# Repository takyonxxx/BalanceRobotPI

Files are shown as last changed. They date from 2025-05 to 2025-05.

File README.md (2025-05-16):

# BalanceRobot

A self-balancing robot project powered by Raspberry Pi 5, featuring precise motor control with 2208 brushless gimbal motors, bidirectional ESCs, Bluetooth connectivity, and a mobile app interface.

## 3D Models

You can view and interact with the 3D models directly in GitHub. The 2208 brushless gimbal motors will be placed inside the wheels for a compact, integrated design:

- [View BalanceRobot Frame STL](https://github.com/takyonxxx/BalanceRobotPI/blob/main/stl/F2BNOQ7J839QTHL.stl)
- [View BalanceRobot Wheel STL](https://github.com/takyonxxx/BalanceRobotPI/blob/main/stl/FDFVE76J839QTI2.stl)

## Overview

BalanceRobot is a two-wheeled self-balancing robot that uses PID control algorithms to maintain equilibrium while allowing for remote control via Bluetooth. The project consists of two major components:

1. **Raspberry Pi 5 Control System**: Handles motion sensing, balance control, and motor management
2. **Mobile App Interface**: Provides remote control and parameter adjustment through a user-friendly touch interface

## Features

- **Real-time Balance Control**: Uses MPU6050 IMU for precise angle measurement and PID control
- **High-precision PWM Generation**: Custom high-resolution PWM threads for precise ESC control
- **Powerful Motor System**: 2X 2208 brushless gimbal motors with bidirectional ESCs for responsive movement
- **Bluetooth Low Energy (BLE) Connectivity**: Remote control and telemetry using GATT server
- **Touch-friendly Mobile Interface**: Intuitive control app optimized for touch screens
- **Parameter Tuning**: Adjust PID parameters in real-time for optimal performance
- **Battery Monitoring**: Built-in voltage monitoring with safety cutoff
- **Diagnostic Features**: Performance monitoring and test modes

## Hardware Requirements

- Raspberry Pi 5 (4 or 3 may work with timing adjustments)
- MPU6050 IMU sensor (connected via I2C)
- 2X 2208 brushless gimbal motors
- Bidirectional ESCs (Electronic Speed Controllers)
- Battery (3S LiPo recommended)
- 3D printed chassis with two wheels
- Mobile device with Bluetooth support (for remote control)

## Motor & ESC Setup

The project uses 2208 brushless gimbal motors, which are ideal for self-balancing robots due to their:
- High torque at low RPM
- Precise control
- Compact design
- Low vibration

The bidirectional ESCs provide:
- Forward and reverse control
- Smooth acceleration and deceleration
- Compatible with standard PWM signal from Raspberry Pi
- Quick response time essential for balance corrections

## Connections and Pinouts

### Raspberry Pi 5 GPIO Connections

| Component | Raspberry Pi Pin | Description |
|---|---|---|
| **MPU6050** | | |
| VCC | 3.3V (Pin 1) | Power for MPU6050 |
| GND | GND (Pin 6) | Ground |
| SCL | GPIO 3 (Pin 5) | I2C Clock |
| SDA | GPIO 2 (Pin 3) | I2C Data |
| | | |
| **ESC1 (Right Motor)** | | |
| Signal | GPIO 18 (Pin 12) | PWM Control Signal |
| VCC | External Power Only | Do NOT connect to Raspberry Pi |
| GND | GND (Pin 14) | Common ground |
| | | |
| **ESC2 (Left Motor)** | | |
| Signal | GPIO 19 (Pin 35) | PWM Control Signal |
| VCC | External Power Only | Do NOT connect to Raspberry Pi |
| GND | GND (Pin 39) | Common ground |
| | | |
| **Status LED** | | |
| LED+ | GPIO 22 (Pin 15) | Status indicator |
| LED- | GND (Pin 34) | via appropriate resistor |

### MPU6050 Orientation

For proper balance control, the MPU6050 should be mounted with:
- X-axis aligned parallel to the wheels (pointing forward)
- Y-axis perpendicular to the wheels (pointing to the side)
- Z-axis pointing upward

### Power Distribution

- Power the Raspberry Pi via its USB-C power input
- Power the ESCs and motors with a separate 3S LiPo battery (11.1V) 
- Ensure common ground between Raspberry Pi and ESC power circuits
- Use appropriate voltage regulators/BECs if powering everything from a single battery

### Wiring Diagram

```
                           +---------------+
                           | Raspberry Pi 5|
                           +---------------+
                           | GPIO2  - SDA  |----+
                           | GPIO3  - SCL  |---+|
                           | GPIO18 - ESC1 |--+ ||
                           | GPIO19 - ESC2 |-+ |||
                           | GPIO22 - LED  |+ ||||
                           | GND           |-|-||||
                           | 3.3V          |--|-|||
                           +---------------+  | |||
                                              | |||
+----------+                  +----------+    | |||
| 3S LiPo  |                  | MPU6050  |<---|-||+
| Battery  |                  +----------+    | ||
+----------+                                  | ||
      |                      +------------+   | ||
      +---+           +------| Right ESC  |<--|-|+
          |           |      +------------+   | |
      +---+-----------+--+                    | |
      |      BEC*     |  |   +------------+   | |
      | (if required) |  +---| Left ESC   |<--|-+
      +--------------+      +------------+    |
                                              |
                            +------------+    |
                            | Status LED |<---+
                            +------------+
```
*BEC: Battery Eliminator Circuit (voltage regulator)

## Software Architecture

The project is built using Qt/C++ for the Raspberry Pi control system and features:

### Raspberry Pi Control System

- **RobotControl Class**: Core control system handling balance, motor control, and communication
- **GattServer**: Manages Bluetooth LE communication with the mobile app
- **High-Precision PWM**: Custom thread-based PWM generation for precise ESC control
- **MPU6050 Interface**: I2C communication with the motion sensor
- **PID Controller**: Implements the balance algorithm with adjustable parameters

### Mobile App

- **Touch-Friendly UI**: Optimized for smartphones with intuitive controls
- **Parameter Adjustment**: Real-time PID parameter tuning with intuitive +/- controls
- **Direction Controls**: Touch-based directional input for robot movement
- **Telemetry Display**: Real-time feedback of robot status and battery level

## Installation

### Raspberry Pi Setup

1. Install required dependencies:

```bash
# Install build essentials
sudo apt-get install build-essential devscripts

# Install Qt6 development packages
sudo apt install qt6-base-dev qt6-base-dev-tools
sudo apt install qt6-connectivity-dev libqt6bluetooth6 qt6-base-dev

# Setup qmake symlink
sudo ln -sf /usr/lib/qt6/bin/qmake6 /usr/local/bin/qmake

# Install I2C development packages
sudo apt install libi2c-dev i2c-tools

# Install WiringPi from source
git clone https://github.com/WiringPi/WiringPi.git
cd WiringPi
sudo ./build
cd ..
```

2. Clone the repository:

```bash
git clone https://github.com/takyonxxx/BalanceRobotPI.git
cd BalanceRobotPI
```

3. Build the project:

```bash
qmake
make
```

4. Run the application:

```bash
sudo ./balancerobot
```

> **Note**: The application requires root privileges to access I2C and GPIO.

### Mobile App Setup

1. Install Qt on your development machine
2. Open the `mobile_app/BalanceRobotRemote.pro` file in Qt Creator qt6.9 Clang arm64-v8a
3. Build and deploy to your Android or iOS device

## Usage

1. Power on the robot and ensure the Raspberry Pi boots properly
2. Launch the control application on the Raspberry Pi
3. Open the mobile app and connect to the robot via Bluetooth
4. Place the robot in an upright position to activate balance mode
5. Arm device and Use the directional controls on the app to move the robot
6. Adjust PID parameters as needed for optimal balance performance

## PID Tuning Guide

The robot's balance performance can be optimized by adjusting the following parameters:

- **P (Proportional)**: Controls the response to the current angle error
- **D (Derivative)**: Controls the response to the rate of change of the angle
- **C (Position)**: Controls the drift correction
- **V (Velocity)**: Controls the damping of movement
- **AC (Angle Correction)**: Fine-tunes the neutral angle

Typical starting values:
- P: 0.1-0.5
- D: 3.0-10.0
- C: 0.0001-0.001
- V: 0.01-0.05
- AC: 0.0-5.0

## Troubleshooting

Common issues and solutions:

1. **Robot doesn't balance**: Ensure MPU6050 is properly connected and calibrated
2. **Motors don't respond**: Check ESC connections and PWM signal generation
3. **Unable to connect via Bluetooth**: Verify Bluetooth service is running and permissions are set
4. **Poor balance performance**: Adjust PID parameters starting with P and D values
5. **Loop overrun warnings**: Increase mainLoop timing to accommodate system capabilities

## License

This project is licensed under the MIT License - see the LICENSE file for details.

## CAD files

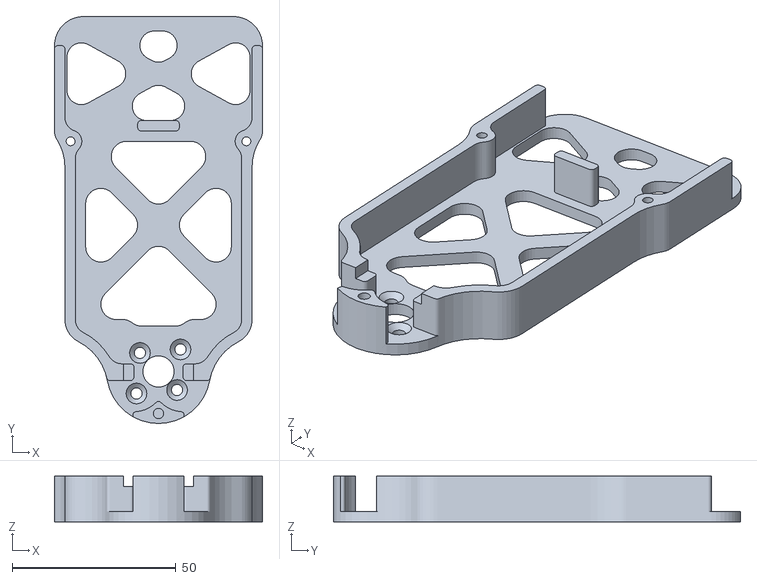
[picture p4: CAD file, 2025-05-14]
stl/F2BNOQ7J839QTHL.stl
63.5 x 124.2 x 14.0

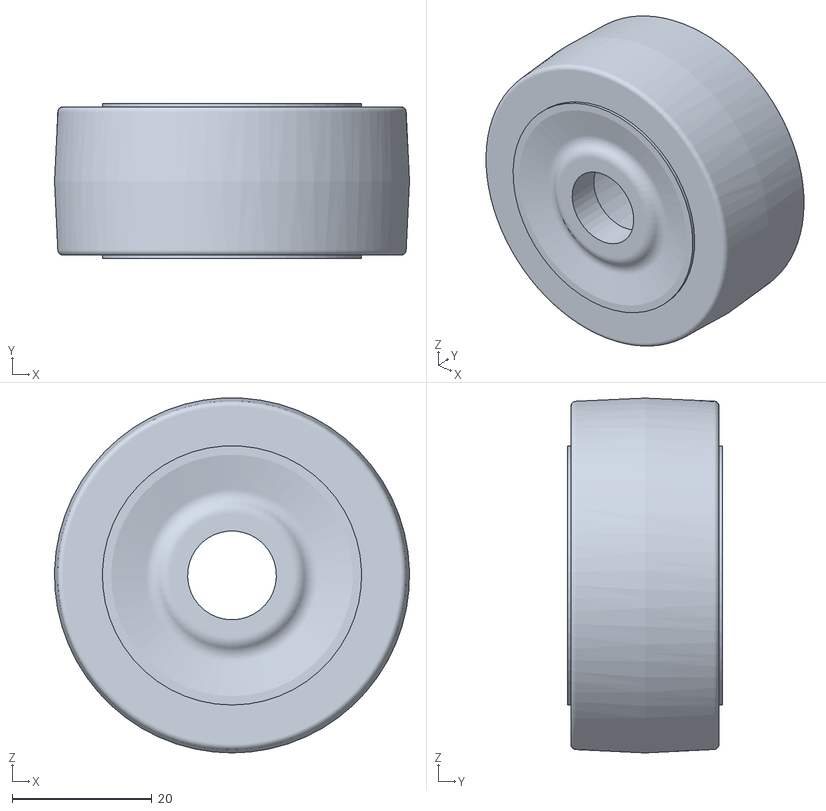
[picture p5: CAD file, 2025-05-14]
stl/FDFVE76J839QTI2.stl
50.8 x 22.2 x 50.8

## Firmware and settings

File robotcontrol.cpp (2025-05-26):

#include "robotcontrol.h"
#include <QDateTime>
#include <cmath>
#include <iostream>
#include <thread>
#include <chrono>
#include <fcntl.h>
#include <unistd.h>
#include <pthread.h>
#include <wiringPi.h>
#include <softPwm.h>
#include "initwiringpi.h"

RobotControl::RobotControl(QObject *parent) : QObject(parent),
    power(false),
    vertical(false),
    batteryDischarged(false),
    robotAngle(0.0f),
    robotSpeed(0.0f),
    robotPosition(0),
    batteryVoltage(0.0f),
    loopTimeMs(0.0f),
    joystickX(0),
    joystickY(0),
    responseRate(1),
    pidInput(0.0f),
    lastPidInput(0.0f),
    lastLastPidInput(0.0f),
    pidOutput(0.0f),
    accelXOffset(0),
    accelYOffset(0),
    gyroZOffset(0),
    gyroFilterEnabled(true),
    filterCount(0),
    pwmRunning(false),
    esc1PulseWidth(ESC_PWM_NEUTRAL),
    esc2PulseWidth(ESC_PWM_NEUTRAL),
    verboseOutput(false)
{
    // Initialize the gyro filter array to zero
    gyroZFilter.fill(0);

    // Initialize wiringPi before creating the RobotControl instance
    if (initWiringPi() < 0) {
        std::cerr << "Failed to initialize wiringPi! Exiting." << std::endl;
        return;
    }

    // Setup timers
    connect(&mainLoopTimer, &QTimer::timeout, this, &RobotControl::mainLoop);
    connect(&batteryTimer, &QTimer::timeout, this, &RobotControl::batteryCheckTimer);
    connect(&telemetryTimer, &QTimer::timeout, this, &RobotControl::sendDataTimer);

    gattServer = GattServer::getInstance();
    if (gattServer)
    {
        qDebug() << "Starting gatt service";
        QObject::connect(gattServer, &GattServer::connectionState, this, &RobotControl::onConnectionStatedChanged);
        QObject::connect(gattServer, &GattServer::dataReceived, this, &RobotControl::onDataReceived);
        gattServer->startBleService();
    }

    // Initialize robot control
    if (!initialize()) {
        std::cerr << "Failed to initialize robot control! Exiting." << std::endl;
        return;
    }
}

RobotControl::~RobotControl()
{
    // Make sure ESCs are at neutral
    stopAllEscs();

    // Stop timers
    mainLoopTimer.stop();
    batteryTimer.stop();
    telemetryTimer.stop();

    // Stop PWM threads
    pwmRunning = false;
    if (pwmThread1.joinable()) {
        pwmThread1.join();
    }
    if (pwmThread2.joinable()) {
        pwmThread2.join();
    }

    delete gattServer;
}

void RobotControl::pwmGeneratorThread(int pin, std::atomic<int>& pulseWidth)
{
    // Period for 50Hz = 20,000 microseconds
    const int periodUs = 20000;

    // Measure sleep overhead once at startup
    std::chrono::high_resolution_clock::time_point start, end;
    start = std::chrono::high_resolution_clock::now();
    std::this_thread::sleep_for(std::chrono::microseconds(100));
    end = std::chrono::high_resolution_clock::now();
    int overhead = std::chrono::duration_cast<std::chrono::microseconds>(end - start).count() - 100;
    overhead = std::max(0, overhead); // Ensure non-negative

    std::cout << "PWM thread for pin " << pin << " started. Sleep overhead: " << overhead << "μs" << std::endl;

    // Set thread to high priority
    pthread_t this_thread = pthread_self();
    struct sched_param params;
    params.sched_priority = sched_get_priority_max(SCHED_FIFO);
    pthread_setschedparam(this_thread, SCHED_FIFO, &params);

    while (pwmRunning) {
        // Get start time for this cycle
        auto cycleStart = std::chrono::high_resolution_clock::now();

        // Get current pulse width
        int width = pulseWidth.load();

        // Generate pulse
        digitalWrite(pin, HIGH);

        // High precision sleep for pulse width
        if (width > overhead) {
            std::this_thread::sleep_for(std::chrono::microseconds(width - overhead));
        }

        // Get precise time after sleep
        auto pulseEnd = std::chrono::high_resolution_clock::now();
        auto elapsedUs = std::chrono::duration_cast<std::chrono::microseconds>(
                             pulseEnd - cycleStart).count();

        // Adjust timing if we slept too long
        if (elapsedUs < width) {
            // Spin-wait for the remaining time
            while (std::chrono::duration_cast<std::chrono::microseconds>(
                       std::chrono::high_resolution_clock::now() - cycleStart).count() < width) {
                // Busy wait
            }
        }

        // Set pin low at exactly the right time
        digitalWrite(pin, LOW);

        // Calculate time spent for the pulse
        auto pulseTime = std::chrono::duration_cast<std::chrono::microseconds>(
                             std::chrono::high_resolution_clock::now() - cycleStart).count();

        // Sleep for the remainder of the period
        int remainingTime = periodUs - pulseTime;
        if (remainingTime > overhead) {
            std::this_thread::sleep_for(std::chrono::microseconds(remainingTime - overhead));
        }

        // Spin-wait to ensure accurate timing for next cycle
        while (std::chrono::duration_cast<std::chrono::microseconds>(
                   std::chrono::high_resolution_clock::now() - cycleStart).count() < periodUs) {
            // Busy wait
        }
    }
}

bool RobotControl::initialize()
{
    std::cout << "Initializing RobotControl..." << std::endl;

    // Note: wiringPi should already be initialized in main()
    // so we don't initialize it here again

    // Initialize LED pin
    pinMode(PIN_LED, OUTPUT);
    digitalWrite(PIN_LED, HIGH);  // Turn on LED

    // Initialize battery ADC pin
    pinMode(PIN_BATTERY, INPUT);

    // Initialize ESC PWM control - silently during initialization
    initEscPwm();

    // Initialize and calibrate MPU6050
    initMpu6050();

    // Perform initial battery check
    batteryTest();
    std::cout << "Battery voltage: " << getBatteryVoltage() << "V" << std::endl;

    // Start timers with adjusted timing for Raspberry Pi 5
    // Main loop at 10ms (100Hz) instead of 4ms (250Hz) to avoid overruns
    mainLoopTimer.start(10);       // Main loop every 10ms (100Hz)
    batteryTimer.start(1000);      // Battery check every 1s
    telemetryTimer.start(130);     // Telemetry every ~130ms

    std::cout << "Initialization complete. Place robot vertical to run." << std::endl;
    return true;
}

void RobotControl::powerOn()
{
    power = true;
    moveRobot(0.0f, 0.0f, 0.0f, 0.0f, 0);
    std::cout << "Robot powered on" << std::endl;
}

void RobotControl::powerOff()
{
    power = false;
    moveRobot(0.0f, 0.0f, 0.0f, 0.0f, 0);
    stopAllEscs();
    std::cout << "Robot powered off" << std::endl;
}

void RobotControl::setFastMode(bool enable)
{
    responseRate = enable ? 2 : 1;
    std::cout << "Fast mode: " << (enable ? "enabled" : "disabled") << std::endl;
}
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

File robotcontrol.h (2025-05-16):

#ifndef ROBOTCONTROL_H
#define ROBOTCONTROL_H

#include <QObject>
#include <QTimer>
#include <cmath>
#include <iostream>
#include <array>
#include <vector>
#include <thread>    // Add this for std::thread
#include <atomic>    // Add this for std::atomic

// External libraries
#include "i2cdev.h"
#include "mpu6050.h"
#include <wiringPi.h>
#include <softPwm.h>
#include "gattserver.h"
#include "message.h"

class RobotControl : public QObject
{
    Q_OBJECT

public:
    explicit RobotControl(QObject *parent = nullptr);
    virtual ~RobotControl();

    // Initialize hardware and sensors
    bool initialize();

    // Control methods
    void powerOn();
    void powerOff();
    void setFastMode(bool enable);
    void setJoystickInput(int16_t x, int16_t y);

    // Unified movement control function
    bool moveRobot(float forward, float lateral, float yaw, float vertical, quint16 buttons);

    void testAllEscs(int durationSeconds);
    void stopAllEscs();
    void directEscControl(int16_t rightThrottle, int16_t leftThrottle);

    // ESC PWM Control
    void setEscPwm(int16_t throttle, int escPin);
    int mapThrottleToPwm(int16_t throttle);

    // Battery information
    float getBatteryVoltage() const;
    bool isBatteryDischarged() const;

    // Loop timing information
    float getLoopTime() const;

    // ESC PWM Pins - Made public so they can be directly referenced
    static constexpr int PIN_ESC_1 = 18;  // First ESC PWM Pin (GPIO 18, Pin 12) - Hardware PWM capable
    static constexpr int PIN_ESC_2 = 12;  // Second ESC PWM Pin (GPIO 12, Pin 32) - Hardware PWM capable

private slots:
    void mainLoop();             // Main control loop
    void batteryCheckTimer();    // Battery check timer
    void sendDataTimer();        // Send telemetry data
    void onConnectionStatedChanged(bool state);
    void onDataReceived(QByteArray data);

signals:
    void telemetryData(float batteryVoltage, float loopTime);
    void batteryLow();
    void loopOverrun(float actualTime);

private:
    // GPIO Pin Configuration
    static constexpr int PIN_LED = 4;     // Status LED Pin 7
    static constexpr int PIN_BATTERY = 0; // Battery voltage ADC Pin

    // PWM Configuration for ESC
    static constexpr int ESC_PWM_FREQUENCY = 50;   // 50 Hz (20ms period) for standard ESCs
    static constexpr int ESC_PWM_RANGE = 2000;     // Using a range of 2000 (makes math easy)
    static constexpr int ESC_PWM_MIN = 1000;       // Minimum pulse width (1000μs = 1ms)
    static constexpr int ESC_PWM_NEUTRAL = 1500;   // Neutral pulse width (1500μs = 1.5ms)
    static constexpr int ESC_PWM_MAX = 2000;       // Maximum pulse width (2000μs = 2ms)

    // Battery Constants
    static constexpr float DISCHARGE_VOLTAGE = 3.0f * 3.0f; // 3 cells at 3.0V each
    static constexpr float RESET_VOLTAGE = 3.0f * 3.7f;     // 3 cells at 3.7V each

    // Balance Robot PID Constants
    float KC = 0.0002f;  // Position feedback gain
    float KV = 0.02f;    // Velocity feedback gain
    float KP = 0.2f;     // Angle gain
    float KD = 0.025f / (2.0f * 0.004f); // Angle velocity gain
    float KAC = 0.0f;
    float KSD = 0.0f;

    static constexpr float PID_OUT_MAX = 100.0f;
    static constexpr float PID_OUT_MIN = -100.0f;
    static constexpr float GYRO_WEIGHT = 0.996f;

    // Private methods
    void initEscPwm();
    void initMpu6050();
    void calibrateGyro();
    void calculateAngle();
    void calculatePid();
    void batteryTest();
    float readBatteryVoltage();
    void debugLog(const std::string& message);

    // PWM generator thread function
    void pwmGeneratorThread(int pin, std::atomic<int>& pulseWidth);

    // Helper method to read MPU6050 data
    bool readMpuData(int16_t &accelX, int16_t &accelY, int16_t &gyroZ);

    void createMessage(uint8_t msgId, uint8_t rw, QByteArray payload, QByteArray *result);
    bool parseMessage(QByteArray *data, uint8_t &command, QByteArray &value, uint8_t &rw);
    void requestData(uint8_t command);
    void sendData(uint8_t command, uint8_t value);
    void sendFloat(uint8_t command, float value);
    void sendString(uint8_t command, QString value);

    GattServer *gattServer = nullptr;
    Message message;

    // Sensor and state variables
    MPU6050 mpu;                  // MPU6050 instance
    QTimer mainLoopTimer;         // Timer for main control loop
    QTimer batteryTimer;          // Timer for battery checks
    QTimer telemetryTimer;        // Timer for telemetry

    bool power;                   // Robot power state
    bool vertical;                // Is robot vertical enough to run
    bool batteryDischarged;       // Battery state

    float robotAngle;             // Current robot angle
    float robotSpeed;             // Current robot speed
    int32_t robotPosition;        // Offset from correct position

    float batteryVoltage;         // Battery voltage
    float loopTimeMs;             // Time taken by main loop

    int16_t joystickX;            // Joystick X input (-100 to 100)
    int16_t joystickY;            // Joystick Y input (-100 to 100)
    uint8_t responseRate;         // Joystick response multiplier

    // PID variables
    float pidInput;
    float lastPidInput;
    float lastLastPidInput;
    float pidOutput;

    // IMU calibration values
    int16_t accelXOffset;
    int16_t accelYOffset;
    int16_t gyroZOffset;
    bool gyroFilterEnabled;
    std::array<int32_t, 32> gyroZFilter;
    uint8_t filterCount;

    // Custom PWM implementation
    std::thread pwmThread1;
    std::thread pwmThread2;
    std::atomic<bool> pwmRunning;
    std::atomic<int> esc1PulseWidth;
    std::atomic<int> esc2PulseWidth;

    bool verboseOutput;           // Controls console output
};

#endif // ROBOTCONTROL_H
